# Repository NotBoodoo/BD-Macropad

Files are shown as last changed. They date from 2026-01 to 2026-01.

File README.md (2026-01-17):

# BD-Macropad
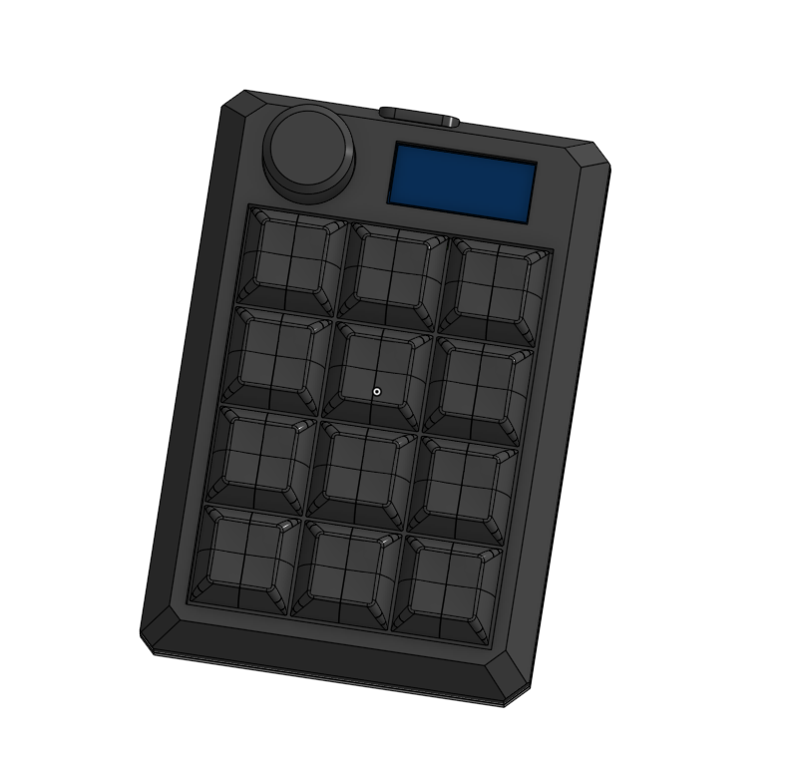
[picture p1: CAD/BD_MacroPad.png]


I wanted to create a macropad that has lot keys, as many as possible. I created a macropad using 12 switches, 1 rp2040, 1 rotary encoder, and 1 Oled 128x32 display.

### Challenges

I used QMK firmware. Firmware was the hardest part. I was constantly having errors while compiling. But after few days of trying i barely managed to compile. But i don't even know it will work or not.
 
### Specifications

BOM: 
- 12x Cherry MX Switches
- 1x XIAO RP2040
- 1x EC11 Rotary encoder
- 1x 0.91 inch OLED display
- 12x Through-hole 1N4148 Diodes
- 12x Blank DSA Keycaps
- 4x M3x6 Bolt
- 4x M3 Heatset

Others:
- QMK Firmware
- Top_Shell.step 
- Bottom_Shell.step
- Knob.step

Schematic            |  PCB         |   Case
:-------------------------:|:-------------------------:|:-------------------------:|
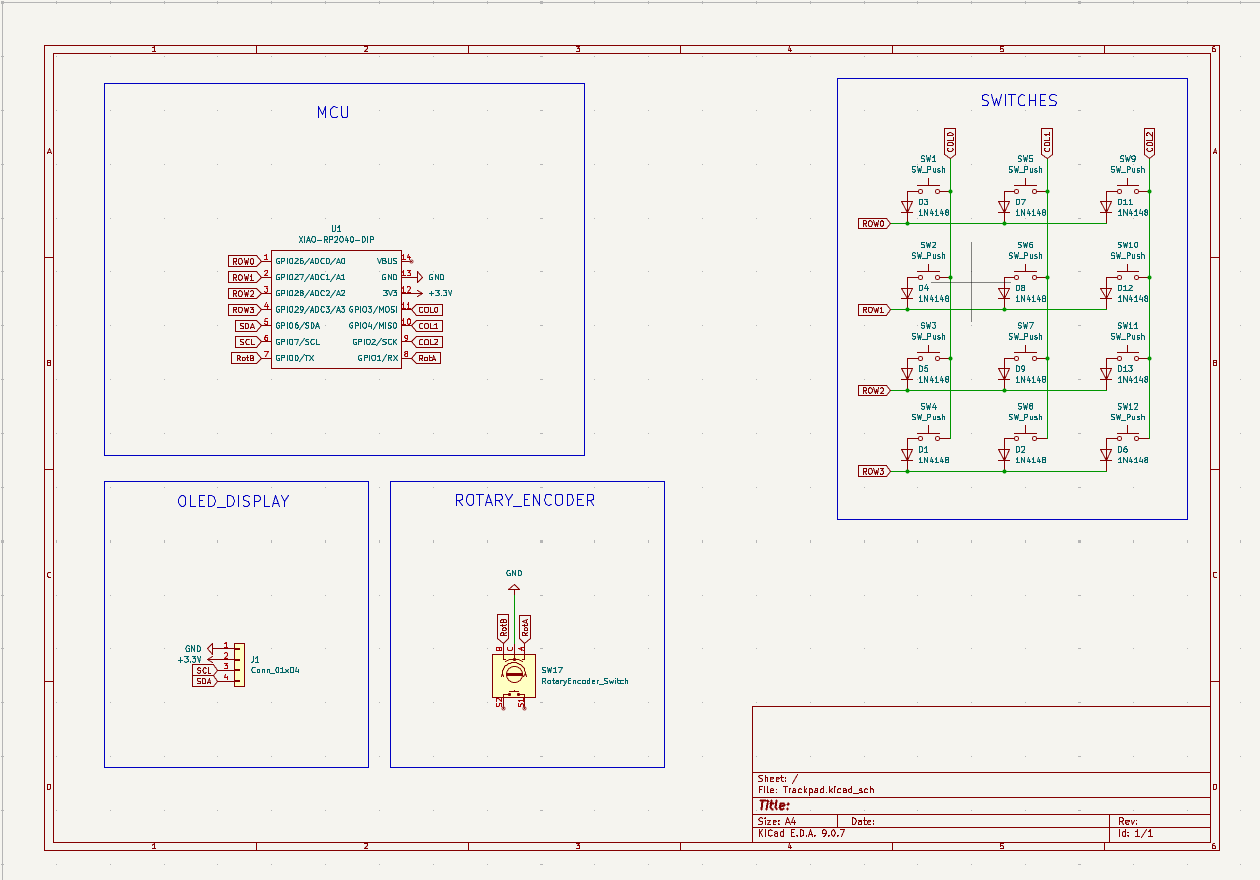
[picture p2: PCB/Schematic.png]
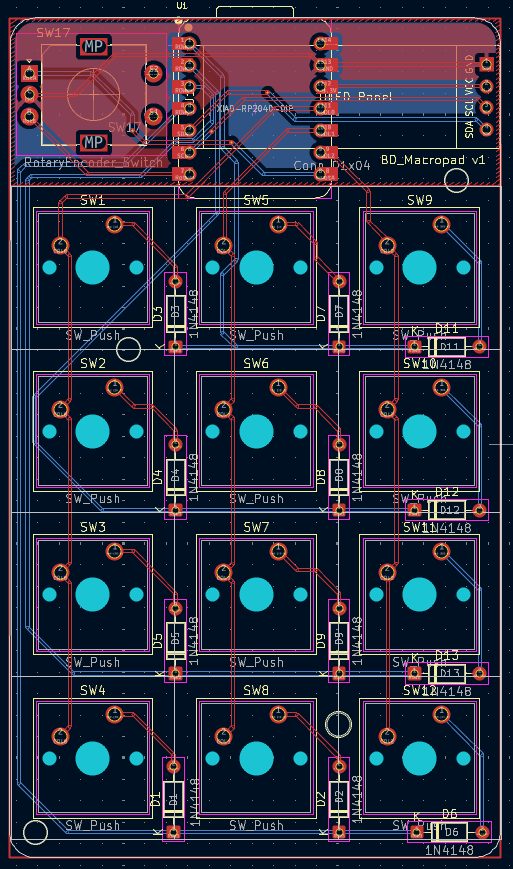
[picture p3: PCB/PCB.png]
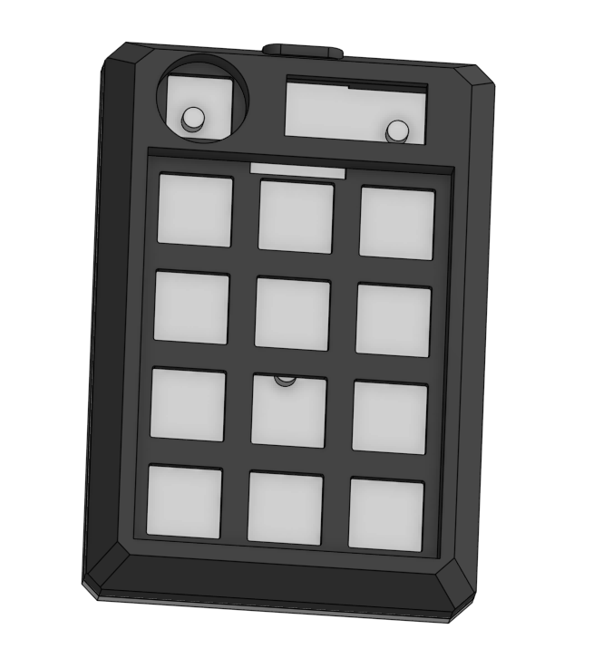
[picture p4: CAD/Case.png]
    |    |

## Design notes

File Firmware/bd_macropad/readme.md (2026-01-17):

# BD_Macropad
Source code for the Firmware. 
Use QMK MSYS (https://msys.qmk.fm/) for Compiling and Flashing. 

# Guide for Compiling
Open QMK MSYS
write "qmk setup" and enter
clone qmk firmware
After cloning qmk_firmware 
Drop the "bd_macropad" folder into "C:\Users\"user"\qmk_firmware\keyboards" folder.
Open QMK MSYS, paste  "qmk compile -kb bd_macropad -km default" and enter.
The Compiled "bd_macropad_default.uf2" file is inside the "qmk_firmware" folder.

## Bootloader

Enter the bootloader in 3 ways:

* **Bootmagic reset**: Hold down the top left key on the left half, or top right key on the right half, and then plug in the USB cable on that keyboard half.
* **Physical reset button**: Double tap the reset button on the XIAO RP2040.
* **Keycode in layout**: Press the key mapped to `QK_BOOT` if it is available.

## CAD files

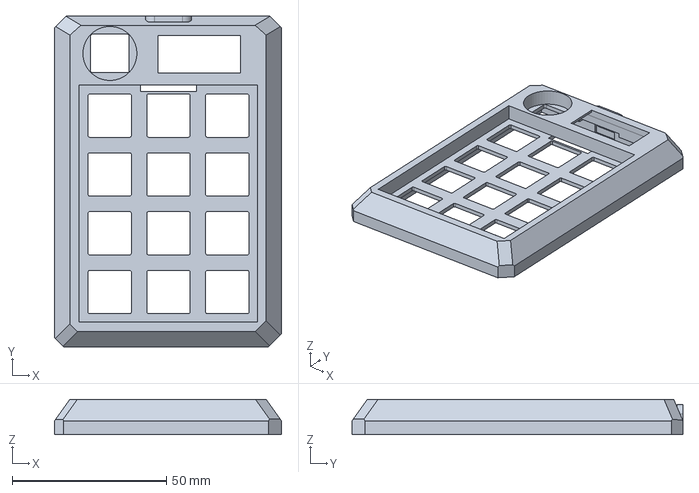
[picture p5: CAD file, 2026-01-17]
CAD/Top_Shell.step
73.6 x 107.2 x 11.5 mm

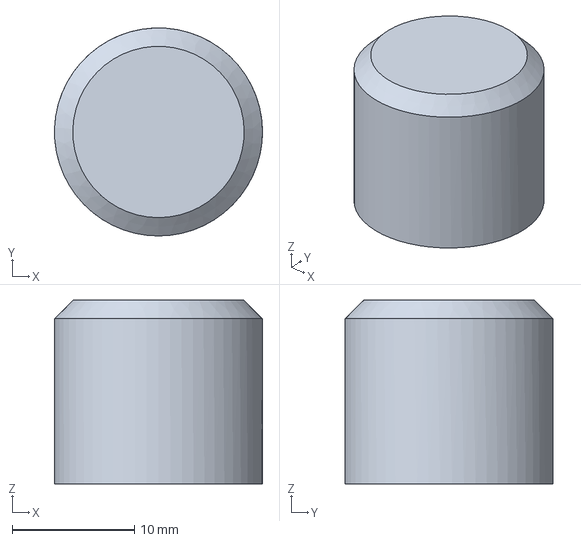
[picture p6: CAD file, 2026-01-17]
CAD/Knob.step
17.0 x 17.0 x 15.0 mm

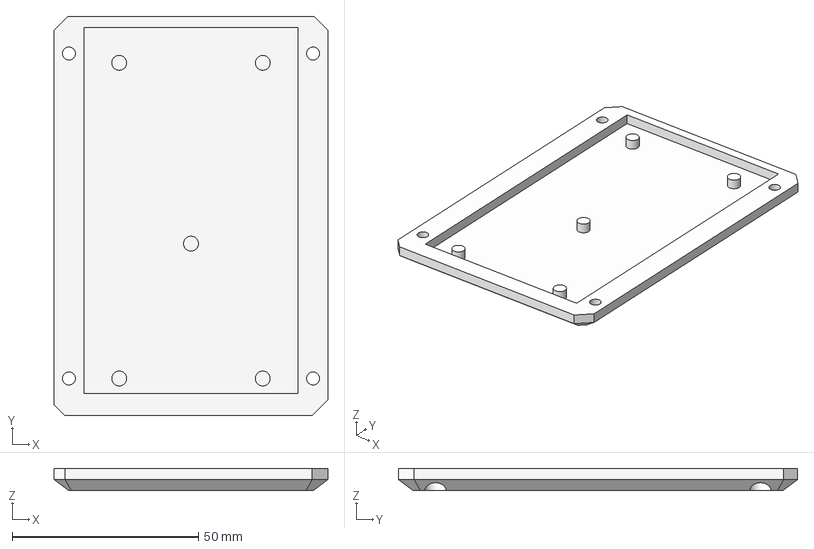
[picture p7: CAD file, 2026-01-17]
CAD/Bottom_Shell.step
73.6 x 107.2 x 6.00 mm

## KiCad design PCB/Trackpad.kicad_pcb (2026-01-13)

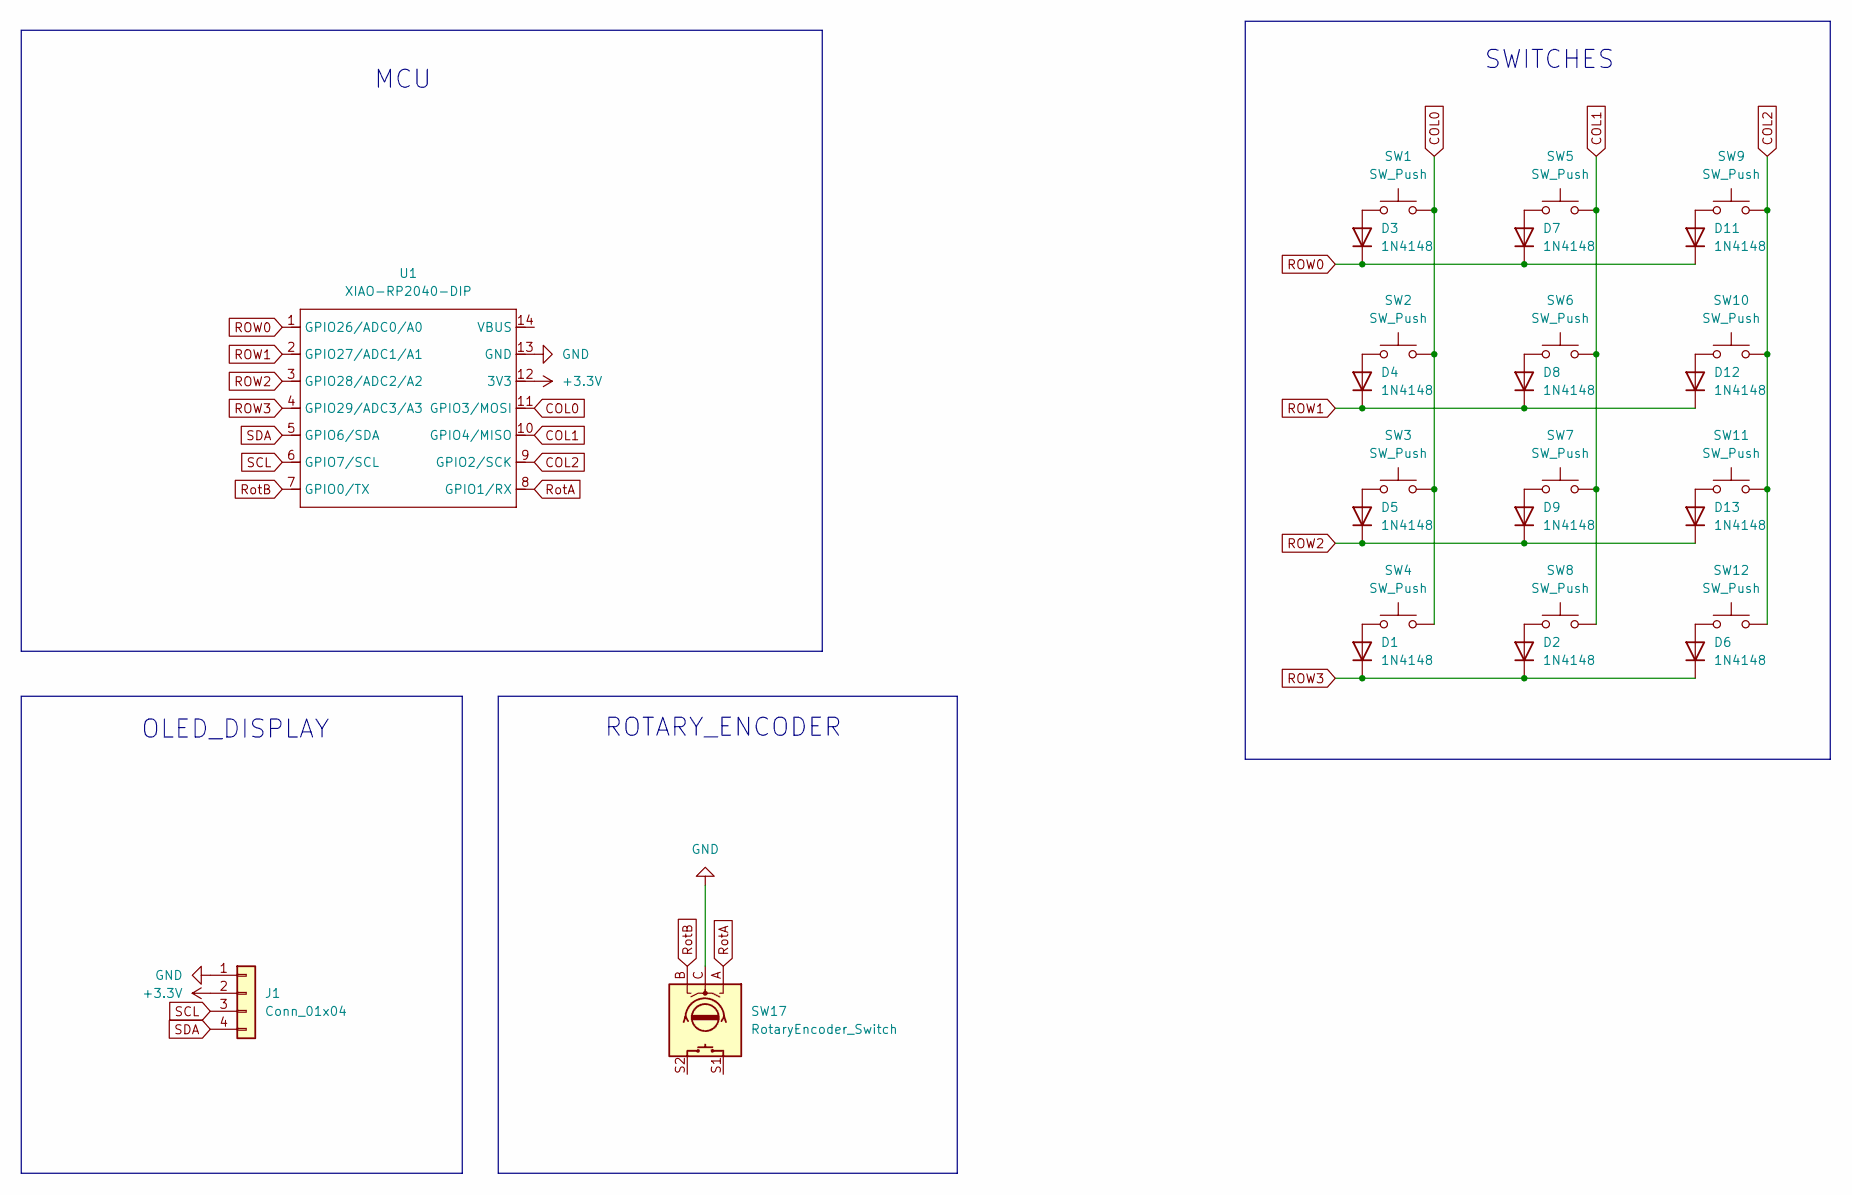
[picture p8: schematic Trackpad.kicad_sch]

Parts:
D1, D2, D3, D4, D5, D6, D7, D8, D9, D11, D12, D13: 1N4148; D_DO-35_SOD27_P7.62mm_Horizontal
J1: Conn_01x04; SSD1306-0.91-OLED-4pin-128x32
SW1, SW2, SW3, SW4, SW5, SW6, SW7, SW8, SW9, SW10, SW11, SW12: SW_Push; SW_Cherry_MX_1.00u_PCB
SW17: RotaryEncoder_Switch; RotaryEncoder_Alps_EC11E-Switch_Vertical_H20mm
U1: XIAO-RP2040-DIP

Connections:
+3.3V: J1.2, U1.12 (3V3)
COL0: SW1.2, SW2.2, SW3.2, SW4.2, U1.11 (GPIO3/MOSI)
COL1: SW5.2, SW6.2, SW7.2, SW8.2, U1.10 (GPIO4/MISO)
COL2: SW9.2, SW10.2, SW11.2, SW12.2, U1.9 (GPIO2/SCK)
GND: J1.1, SW17.C, U1.13 (GND)
unnamed: D1.2 (A), SW4.1
unnamed: D2.2 (A), SW8.1
unnamed: D3.2 (A), SW1.1
unnamed: D4.2 (A), SW2.1
unnamed: D5.2 (A), SW3.1
unnamed: D6.2 (A), SW12.1
unnamed: D7.2 (A), SW5.1
unnamed: D8.2 (A), SW6.1
unnamed: D9.2 (A), SW7.1
unnamed: D11.2 (A), SW9.1
unnamed: D12.2 (A), SW10.1
unnamed: D13.2 (A), SW11.1
ROW0: D3.1 (K), D7.1 (K), D11.1 (K), U1.1 (GPIO26/ADC0/A0)
ROW1: D4.1 (K), D8.1 (K), D12.1 (K), U1.2 (GPIO27/ADC1/A1)
ROW2: D5.1 (K), D9.1 (K), D13.1 (K), U1.3 (GPIO28/ADC2/A2)
ROW3: D1.1 (K), D2.1 (K), D6.1 (K), U1.4 (GPIO29/ADC3/A3)
RotA: SW17.A, U1.8 (GPIO1/RX)
RotB: SW17.B, U1.7 (GPIO0/TX)
SCL: J1.3, U1.6 (GPIO7/SCL)
SDA: J1.4, U1.5 (GPIO6/SDA)

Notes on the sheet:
MCU
SWITCHES
ROTARY_ENCODER
OLED_DISPLAY

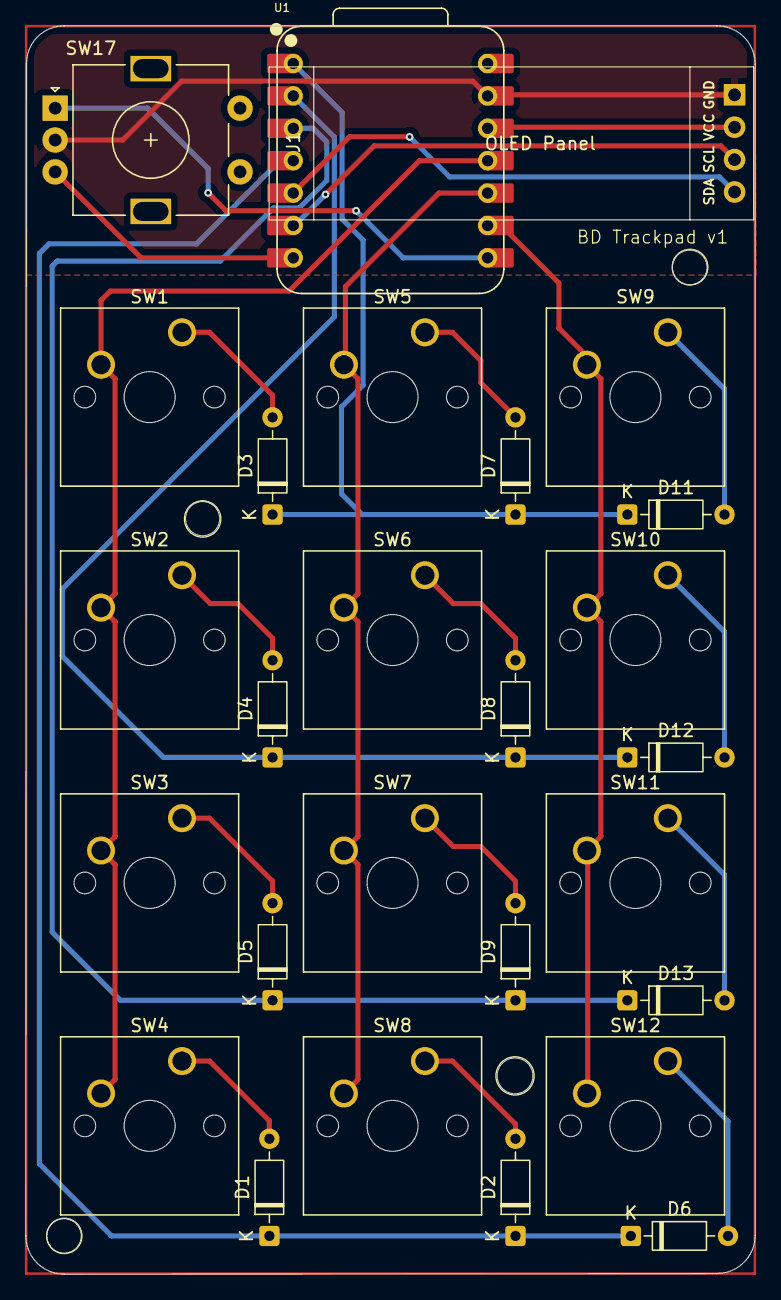
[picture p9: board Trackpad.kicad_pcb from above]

Board: 2 copper layers, 57.2 x 97.9 mm, 27 parts (0 on the bottom side), 25 nets.

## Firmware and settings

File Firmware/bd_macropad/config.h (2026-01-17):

#pragma once

/* Double tap reset button to enter bootloader */
#define RP2040_BOOTLOADER_DOUBLE_TAP_RESET
#define RP2040_BOOTLOADER_DOUBLE_TAP_RESET_LED GP17
#define RP2040_BOOTLOADER_DOUBLE_TAP_RESET_TIMEOUT 500U

#define I2C1_SDA_PIN GP6
#define I2C1_SCL_PIN GP7

#ifdef OLED_ENABLE
#   define OLED_DISPLAY_128X32
#   define OLED_TIMEOUT 60000
#   define OLED_BRIGHTNESS 128
#endif

#define DEBOUNCE 5
